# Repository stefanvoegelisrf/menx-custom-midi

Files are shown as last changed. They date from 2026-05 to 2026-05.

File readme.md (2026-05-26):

# Custom MIDI controller

This repository contains the code for my custom MIDI controller. The goal of the project is to make a face-shaped MIDI controller that is using I2C components and an ESP32. Code is written using Arduino IDE.

In this readme you can find the parts I used in the project, links to the project setup and helpful resources that I used in this project.

- [Custom MIDI controller](#custom-midi-controller)
  - [Project setup](#project-setup)
  - [Parts used in this project](#parts-used-in-this-project)
    - [Microcontroller - Waveshare ESP32-S3](#microcontroller---waveshare-esp32-s3)
      - [Documentation](#documentation)
    - [Slide potentiometers - Adafruit NeoSlider](#slide-potentiometers---adafruit-neoslider)
      - [Documentation](#documentation-1)
    - [Rotary Encoders - Adafruit Rotary Encoder](#rotary-encoders---adafruit-rotary-encoder)
      - [Documentation](#documentation-2)
    - [Buttons - Adafruit NeoKey 1x4](#buttons---adafruit-neokey-1x4)
      - [Documentation](#documentation-3)
  - [What is I2C](#what-is-i2c)
    - [I2C and Arduino](#i2c-and-arduino)
    - [I2C and Adafruit](#i2c-and-adafruit)
  - [Resources](#resources)

## Project setup

I have split the project setup into two parts.

[Project setup - Hardware](./project-setup-hardware.md) covers the hardware part of the project: 3D printing the controller case, soldering the parts, soldering the I2C addresses and connecting the components.

[Project setup - Software](./project-setup-software.md) covers the software part of the project: Setting up the development environment and code explanations.

## Parts used in this project

This project makes use of components by Adafruit which are connected via I2C (STEMMAT QT / QWIIC) for controlling MIDI. The components are connected to an ESP32.

### Microcontroller - Waveshare ESP32-S3

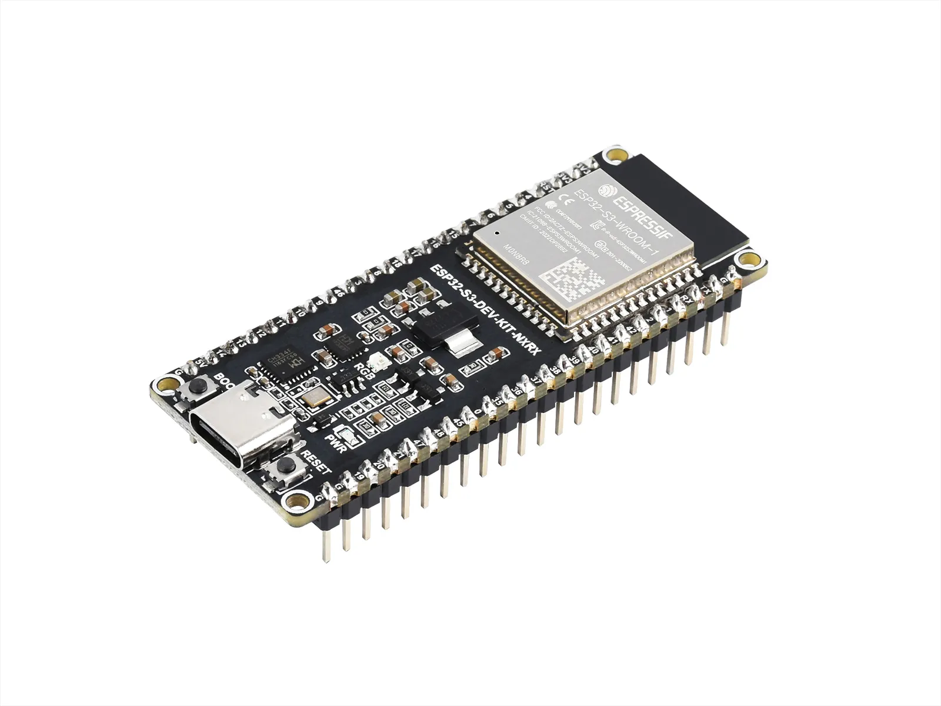
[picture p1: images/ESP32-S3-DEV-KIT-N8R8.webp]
Waveshare ESP32-S3 Product Image


> Product Link: [waveshare.com - ESP32-S3-DEV-KIT-NXRX](https://docs.waveshare.com/ESP32-S3-DEV-KIT-N8R8)

This ESP32 is used for receiving the signals from the components used, handles controlling the LEDs of the components and sends the MIDI signals over USB.

Number of components in this project: 1

#### Documentation

- [waveshare.com - ESP32-S3-DEV-KIT-NXRX](https://docs.waveshare.com/ESP32-S3-DEV-KIT-N8R8)

### Slide potentiometers - Adafruit NeoSlider

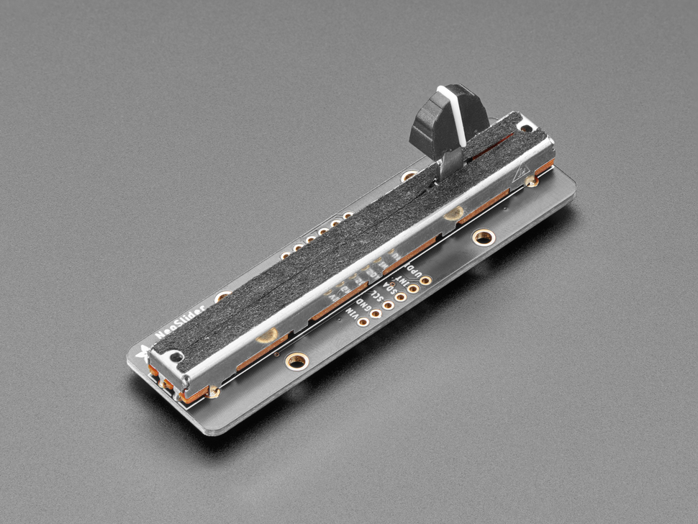
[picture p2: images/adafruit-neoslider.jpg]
Adafruit NeoSlider Product Image


> Product Link: [adafruit.com - Adafruit NeoSlider I2C QT Slide Potentiometer with 4 NeoPixels - STEMMA QT / Qwiic](https://www.adafruit.com/product/5295)

The slide potentiometers are used for representing the eyebrows of the face. I use custom slider caps. The 3D print file for these can be found [here - TODO: add link]().

Number of components in this project: 2

#### Documentation

- [learn.adafruit.com - Adafruit Neoslider](https://cdn-learn.adafruit.com/downloads/pdf/adafruit-neoslider.pdf)
- [learn.adafruit.com - Adafruit NeoSlider Downloads](https://learn.adafruit.com/adafruit-neoslider/downloads)

### Rotary Encoders - Adafruit Rotary Encoder

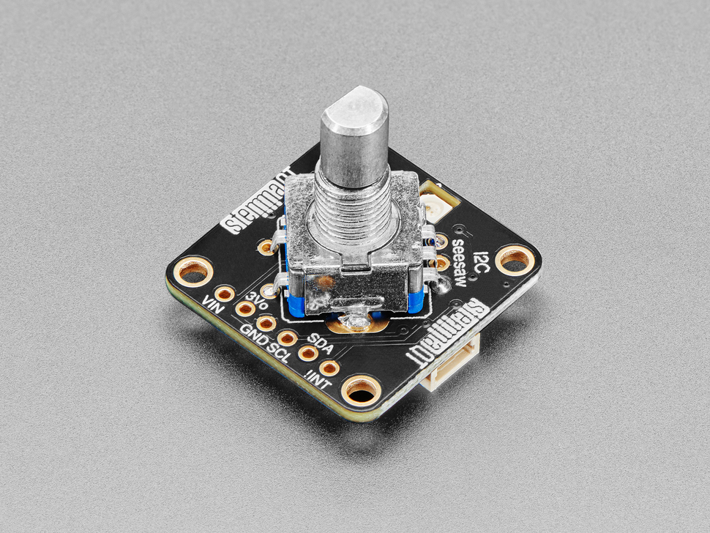
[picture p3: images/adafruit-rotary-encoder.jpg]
Adafruit Rotary Encoder Product Image


> Product Link: [Adafruit I2C Stemma QT Rotary Encoder Breakout with Encoder - STEMMA QT / Qwiic](https://www.adafruit.com/product/5880)

The rotary encoders are used for representing the eyes, noseholes and earrings of the face. I use custom encoder caps. The 3D print file for these can be found here: [EarringRotary.stl](./3d-print-parts/EarringRotary.stl), [Eyeknob_1.stl](./3d-print-parts/Eyeknob_1.stl) and [NoseRotary.stl](./3d-print-parts/NoseRotary.stl).

Number of components in this project: 6

#### Documentation

- [learn.adafruit.com - Adafruit I2C QT Rotary Encoder](https://cdn-learn.adafruit.com/downloads/pdf/adafruit-i2c-qt-rotary-encoder.pdf)
- [learn.adafruit.com - Adafruit I2C QT Rotary Encoder Downloads](https://learn.adafruit.com/adafruit-i2c-qt-rotary-encoder/downloads)

### Buttons - Adafruit NeoKey 1x4

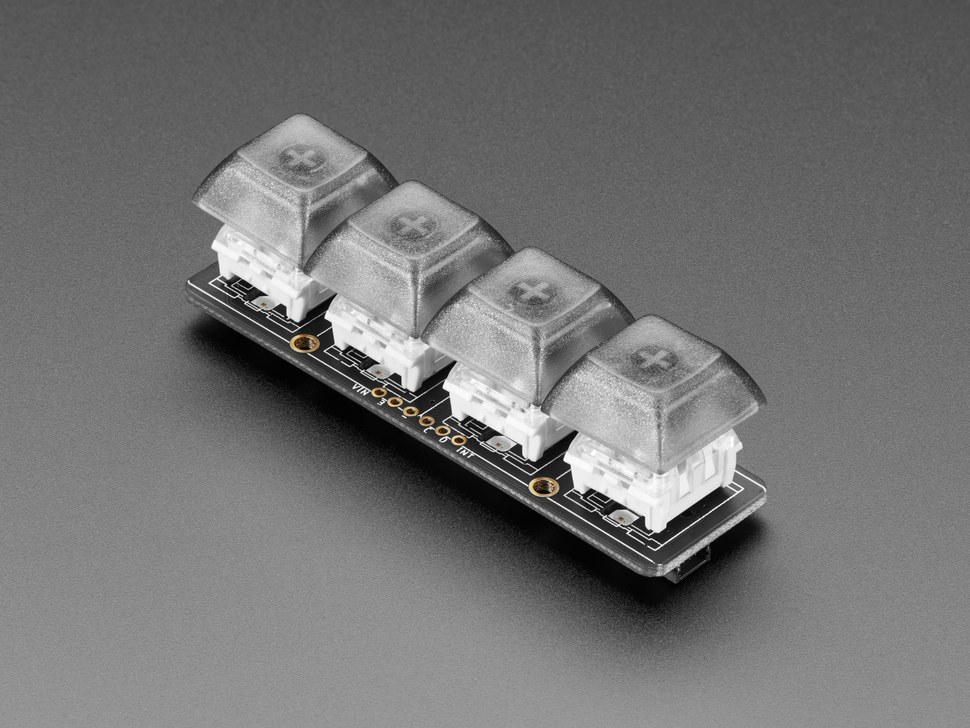
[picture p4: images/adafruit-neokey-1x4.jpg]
Adafruit NeoKey 1x4 Product Image


> Product Link: [adafruit.com - NeoKey 1x4 QT I2C - Four Mechanical Key Switches with NeoPixels - STEMMA QT / Qwiic](https://www.adafruit.com/product/4980)

The buttons are used for representing the teeth of the face. I use standard parts for the key switches and key caps. These are:
- [adafruit.com - Kailh Mechanical Key Switches - Linear Black - 10 pack - Cherry MX Black Compatible](https://www.adafruit.com/product/4953)
- [adafruit.com - Translucent Keycaps for MX Compatible Switches - 10 pack](https://www.adafruit.com/product/4956)

Number of components in this project: 2

#### Documentation

- [learn.adafruit.com - NeoKey 1x4 QT I2C](https://learn.adafruit.com/neokey-1x4-qt-i2c)
- [learn.adafruit.com - NeoKey 1x4 QT I2C Downloads](https://learn.adafruit.com/neokey-1x4-qt-i2c/downloads)

## What is I2C

Inter-integrated circuit (I2C) is a protocol used to connect and transfer data between my main processor (ESP32) and my components (Rotary encoders, sliders and buttons) using simple wiring.

Each component has a unique identification number assigned to it, so I can send or request data from the correct component.

I2C uses two lines to connect the devices:
- SDA (Serial Data): The actual data sent back and forth between processor and components
- SCL (Serial Clock): The pulsing signal to keep the devices synchronized

### I2C and Arduino

I2C in Arduino is handled with the [Wire Library](https://docs.arduino.cc/learn/communication/wire/#wire-library).

### I2C and Adafruit

The components that I use are from Adafruit and they have 5 connectors:
- VIN: Power pin, which can be supplied with 3 - 5 VDC. The components can regulate the voltage.
- 3Vo: 3.3V output from the voltage regulator
- GND: Ground
- SCL: I2C clock
- SDA: I2C data

## Resources

- [learn.adafruit.com - Adafruit STEMMA & STEMMA QT](https://learn.adafruit.com/introducing-adafruit-stemma-qt/what-is-stemma)
- [learn.adafruit.com - I2C address list](https://learn.adafruit.com/i2c-addresses/the-list)
- [docs.arduino.com - Inter-Integrated Circuit (I2C) Protocol](https://docs.arduino.cc/learn/communication/wire/)

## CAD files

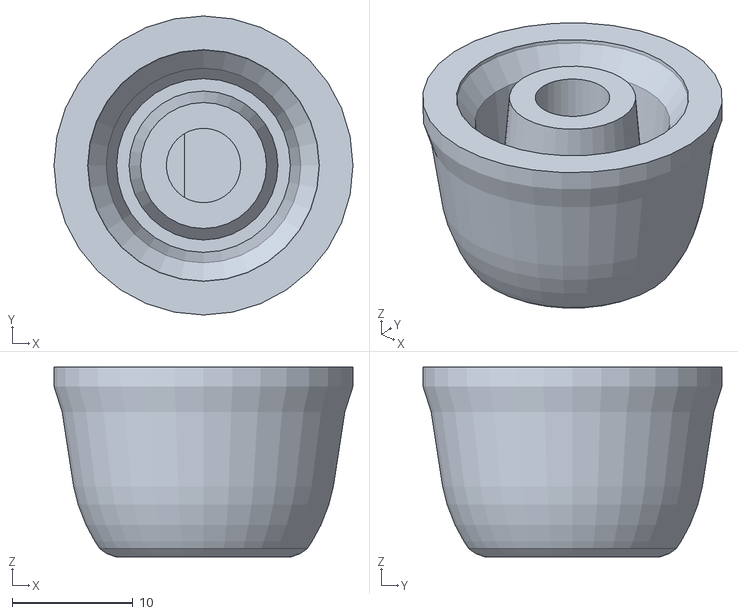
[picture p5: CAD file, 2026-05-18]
3d-print-parts/NoseRotary.stl
24.8 x 24.8 x 15.7

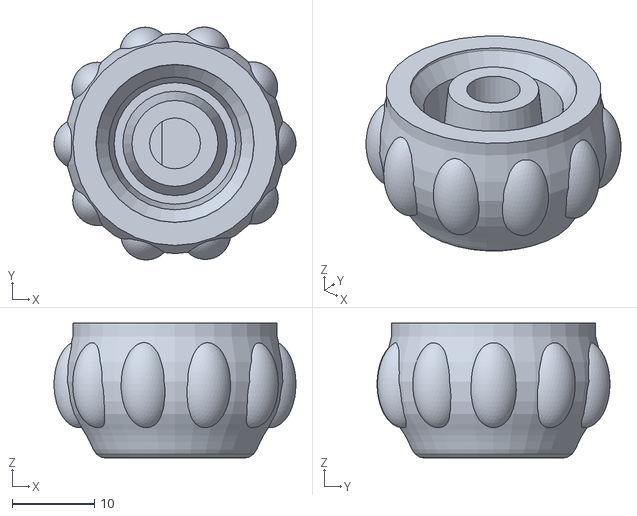
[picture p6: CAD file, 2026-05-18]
3d-print-parts/EarringRotary.stl
29.4 x 28.3 x 16.4

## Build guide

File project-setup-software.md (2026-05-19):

# Project Setup - Software

Below is a description of what is required to get the software of this project to work.

- [Project Setup - Software](#project-setup---software)
  - [Prerequisites](#prerequisites)
    - [Install Arduino IDE](#install-arduino-ide)
    - [Install Adafruit Seesaw library](#install-adafruit-seesaw-library)
    - [Install MIDI Library](#install-midi-library)
    - [Install ESP32 Boards](#install-esp32-boards)
    - [MIDI definition](#midi-definition)
      - [Data Value Mapping](#data-value-mapping)
      - [MIDI assignment](#midi-assignment)
  - [Troubleshooting and helpful stuff I learned](#troubleshooting-and-helpful-stuff-i-learned)
    - [No serial messages received](#no-serial-messages-received)
    - [No seesaw chip found](#no-seesaw-chip-found)
    - [Testing MIDI](#testing-midi)
    - [Enable MIDI](#enable-midi)
    - [Automating the build process and making it configurable](#automating-the-build-process-and-making-it-configurable)
  - [Resources](#resources)

## Prerequisites

In order to get started with the development, we need to set up a few things first.

### Install Arduino IDE

To develop this project, we use the Arduino IDE, as it is simple to use and can help us bundling the code correctly for our ESP32.

To install it, download it from [arduino.cc](https://www.arduino.cc/en/software/) and follow the installation process.

### Install Adafruit Seesaw library

The Adafruit components used in this project all have seesaw chips, so we need to install the seesaw library inside of the Arduino IDE to communicate with these chips.

To install it, go to the library manager and search for `adafruit seesaw` and install the library.

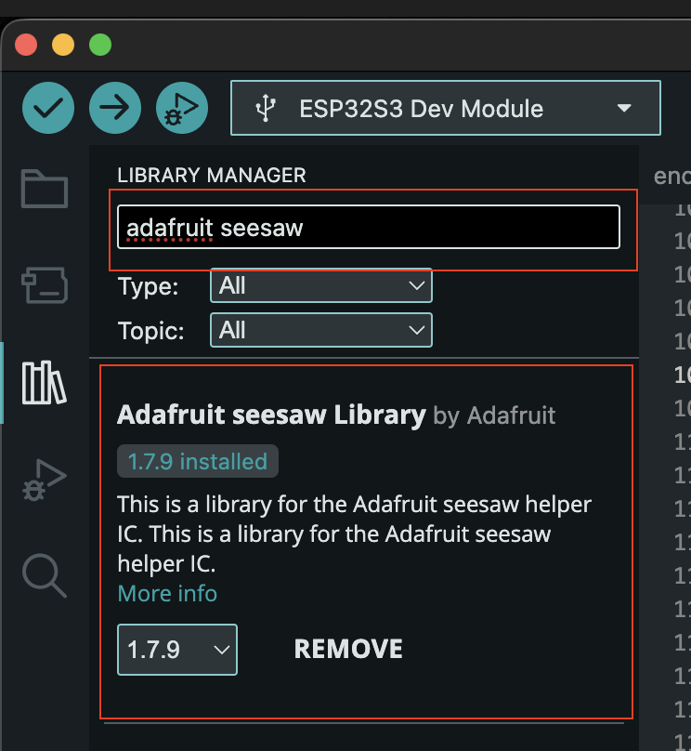
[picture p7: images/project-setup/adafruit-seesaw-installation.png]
Screenshot for Adafruit Seesaw library installation inside of Arduino IDE


### Install MIDI Library

This project transmits the values of the components via MIDI over USB and MIDI over BLE. A simple library to achieve this is called [Control-Surface](https://github.com/tttapa/Control-Surface) which also supports ESP32.

To install it, go to the library manager and search for `control surface`and install the library.

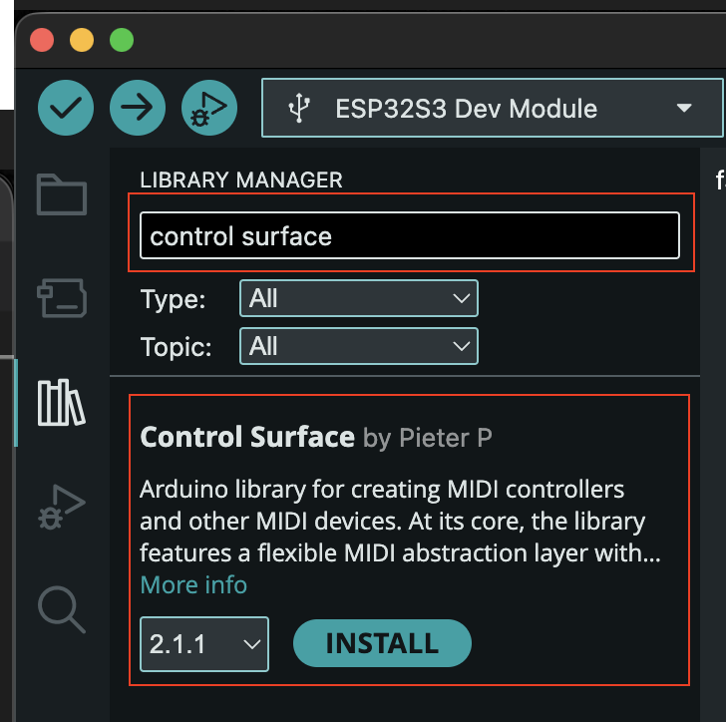
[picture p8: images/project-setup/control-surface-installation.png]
Screenshot for Control Surface library installation inside of Arduino IDE


### Install ESP32 Boards

As we use an ESP32 board in this project, we need to add the board configuration.

To do so, open the board manager and search for `esp32` and install the board configurations.

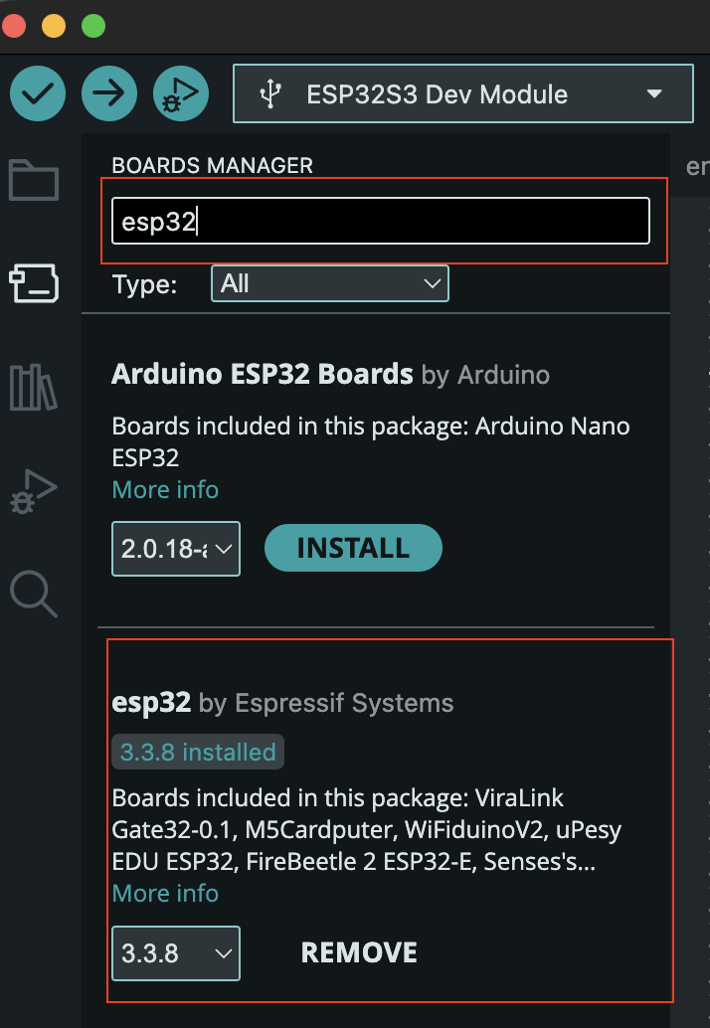
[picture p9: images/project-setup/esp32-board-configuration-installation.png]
Screenshot for ESP32 board configuration installation inside of Arduino IDE


### MIDI definition

My layout enables me to do a MIDI mapping to two channels. Like this I can assign 3 rotary encoders, 1 slider and 4 keys to each channel.

| MIDI Channel 1 | MIDI Channel 2 |
| --- | --- |
| Left Slider | Right Slider |
| Left Eye Rotary Encoder  | Right Eye Rotary Encoder  |
| Left Nose Rotary Encoder | Right Nose Rotary Encoder |
| Left Ear Rotary Encoder  | Right Ear Rotary Encoder  |
| Top 4 Keys | Bottom 4 Keys |

#### Data Value Mapping

The values that I receive from my components need to be mapped to MIDI values. The table below lines out how this is done:

| Hardware Action | MIDI Message Type | Data 1 (Identification) | Data 2 (Value) |
| --- | --- | --- | --- |
| Slider Movement | Control Change (CC) | CC Number | 0 to 127 |
| Encoder Turn Right | Control Change (CC) | CC Number | 1 |
| Encoder Turn Left  | Control Change (CC) | CC Number | 127 |
| Encoder/Key Press  | Note On or CC | Note/CC Number | 127 |
| Encoder/Key Lift | Note Off or CC | Note/CC Number | 0 |

#### MIDI assignment

Each of the components has to send unique values, the table below outlines the assigned values. This is the same for both MIDI channels.

| Component | Control Change | Note |
| --- | --- | ---- |
| Slider | 10 | |
| Eye Rotary Encoder  | 20 (Rotation), 21 (Switch) | 36 |
| Nose Rotary Encoder | 22 (Rotation), 23 (Switch) | 37 |
| Ear Rotary Encoder  | 24 (Rotation), 25 (Switch) | 38 |
| Key 1 | 26 | 40 |
| Key 2 | 27 | 41 |
| Key 3 | 28 | 42 |
| Key 4 | 29 | 43 |

## Troubleshooting and helpful stuff I learned

I have run into some issues in this project and here is a list of issues that I ran into, so if I run into them again, I know what the issue is and how to solve it.

### No serial messages received

I had the issue that I did not receive serial messages from my board, which sucks when trying to debug the project.

The issue was, that I had the setting `USB CDC On Boot` on `Disabled`. To receive the serial messages, set this to `Enabled`.

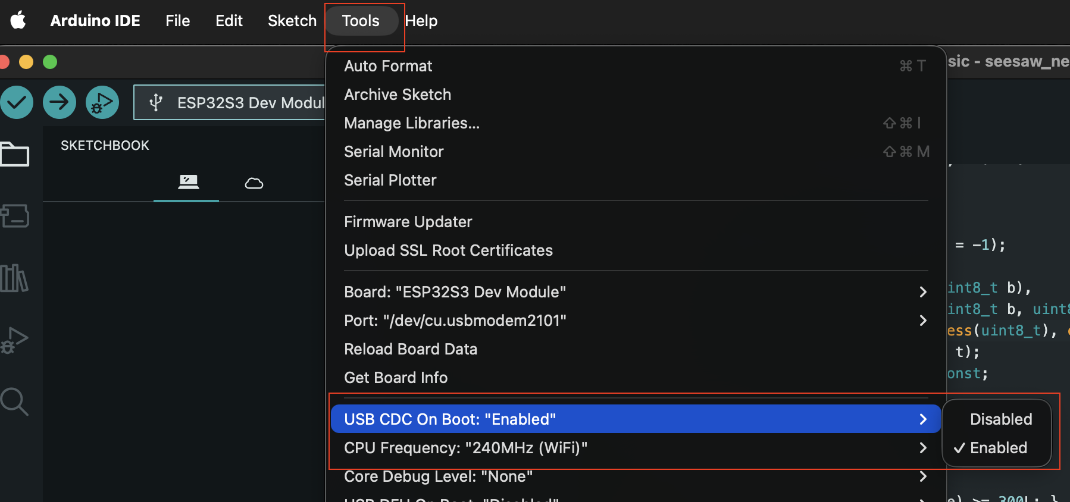
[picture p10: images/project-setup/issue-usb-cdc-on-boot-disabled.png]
Screenshot of setting USB CDC On Boot to Enabled inside of Arduino IDE


### No seesaw chip found

When using an ESP32, we can define the I2C pins freely and most likely, they will not be the standard I2C pins. To change this, we can set the pins manually in the Wire library and then pass the pointer of Wire to the Adafruit seesaw library.

```cpp
#define I2C_SDA 14
#define I2C_SCL 13

....

Adafruit_seesaw Sliders[2] = {
  Adafruit_seesaw(&Wire1),
  Adafruit_seesaw(&Wire1)
};

Adafruit_NeoKey_1x4 NeoKeyButtons[KEY_ROWS][KEY_COLUMNS / 4] = {
  { Adafruit_NeoKey_1x4(BUTTONS1_ADDRESS, &Wire1) },
  { Adafruit_NeoKey_1x4(BUTTONS2_ADDRESS, &Wire1) },
};

...

void setup() {
  // Set ESP32 pins manually, as they are not on the default pins
  Wire1.setPins(I2C_SDA, I2C_SCL);
}
```

### Testing MIDI

In order to troubleshoot if any and if the correct MIDI messages arrive on the receiving device, we can use a MIDI monitor application, e.g. [snoize.com. - MIDI Monitor](https://www.snoize.com/MIDIMonitor/)

### Enable MIDI

In order for the ESP32 to act as a MIDI device, we need to change some settings in Arduino IDE.

First, we need to set the USB mode to TinyUSB:

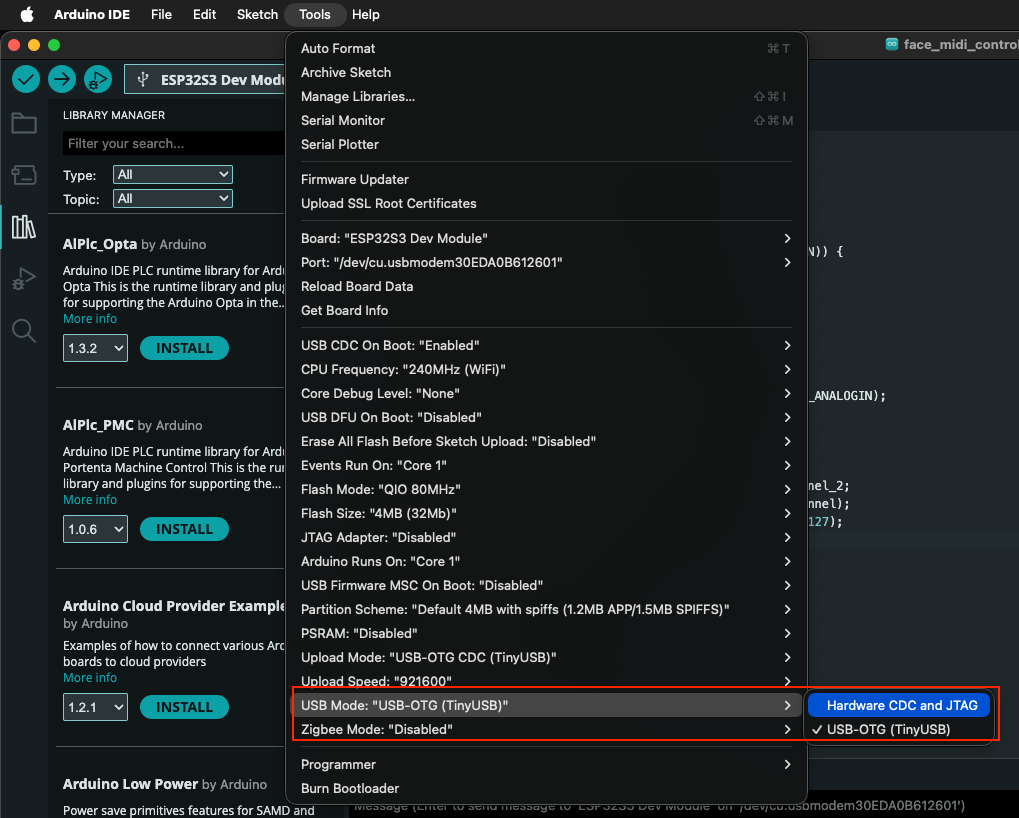
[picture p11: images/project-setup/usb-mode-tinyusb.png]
Screenshot of setting USB mode to TinyUSB inside of Arduino IDE


Then, to be able to upload new firmware onto the controller, we also need to set the upload mode to TinyUSB:

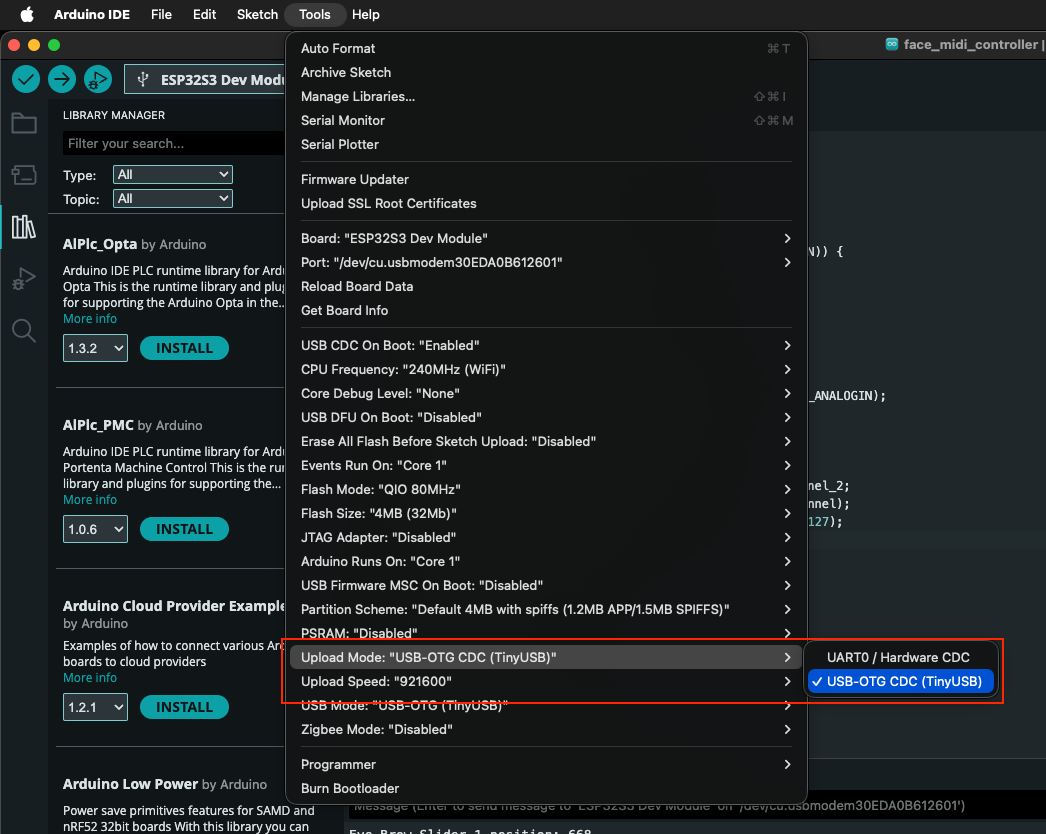
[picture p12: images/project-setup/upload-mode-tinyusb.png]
Screenshot of setting upload mode to TinyUSB inside of Arduino IDE


### How to connect MIDI BLE

In order to connect a MIDI device via BLE, we need to use the `Audio MIDI Setup` application of MacOS and the open the `MIDI Studio` via `Window` -> `Show MIDI Studio`.

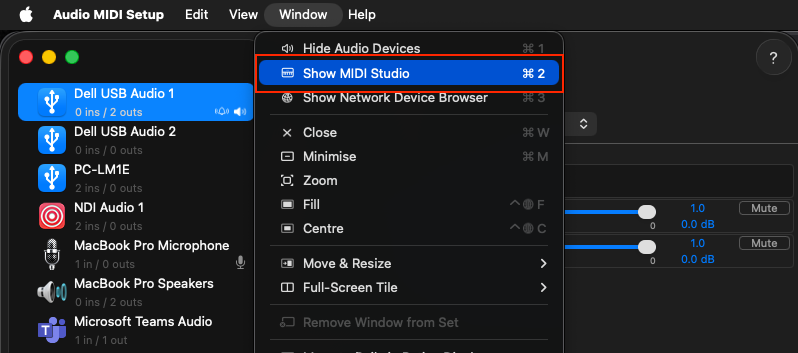
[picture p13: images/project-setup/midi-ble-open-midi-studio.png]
Screenshot showing how to open MIDI Studio


Once we have MIDI Studio open, we can click on the Bluetooth icon to search for our device and connect to it.

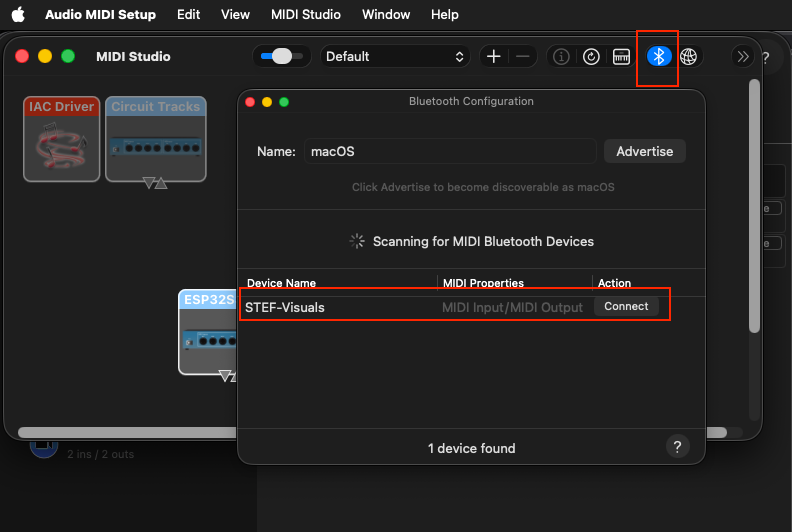
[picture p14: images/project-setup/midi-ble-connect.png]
Screenshot showing how to connect to MIDI BLE device


### Automating the build process and making it configurable

https://platformio.org/

## Resources

- [learn.adafruit.com - Adafruit Seesaw](https://learn.adafruit.com/adafruit-seesaw-atsamd09-breakout/overview)
- [learn.adafruit.com - Adafruit NeoSlider Arduino](https://learn.adafruit.com/adafruit-neoslider/arduino)
- [docs.waveshare.com - ESP32-S3-DEV-KIT-N8R8 Development Environment Setup Arduino](https://docs.waveshare.com/ESP32-S3-DEV-KIT-N8R8/Development-Environment-Setup-Arduino)
- [docs.waveshare.com - ESP32 Arduino IDE Setup](https://docs.waveshare.com/ESP32-Arduino-Tutorials/Arduino-IDE-Setup)
- [learn.adafruit.com - Arduino MIDI Example](https://learn.adafruit.com/adafruit-midi-featherwing/arduino-midi-example)
- [learn.adafruit.com - MIDI for Makers](https://learn.adafruit.com/midi-for-makers/overview)
- [tttapa.github.io - Control Surface Documentation](https://tttapa.github.io/Control-Surface/Doxygen/index.html)

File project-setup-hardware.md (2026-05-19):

# Project setup - Hardware

## 3D Printing

In this project, I have designed a custom case along with custom slider and rotary caps.

### Case

### Rotary encoder caps

I have not designed the rotary encoder caps from the ground up. Instead I have used freely available models and customized them to my liking.

In my project, the rotary encoders represent different parts of a face: eyes, nose holes and ear rings.

#### Print settings

In order to get fine details of the controller, I have set the layer height to the lowest possible setting.

In order to get good stability, I have set the infill density to a higher value.
TODO: add print settings(layer height, dense infill, no supports)

#### Eyes

> Base model: [thingiverse.com - Knob D shape rotary encoder by nanoBorg88](https://www.thingiverse.com/thing:3904056)

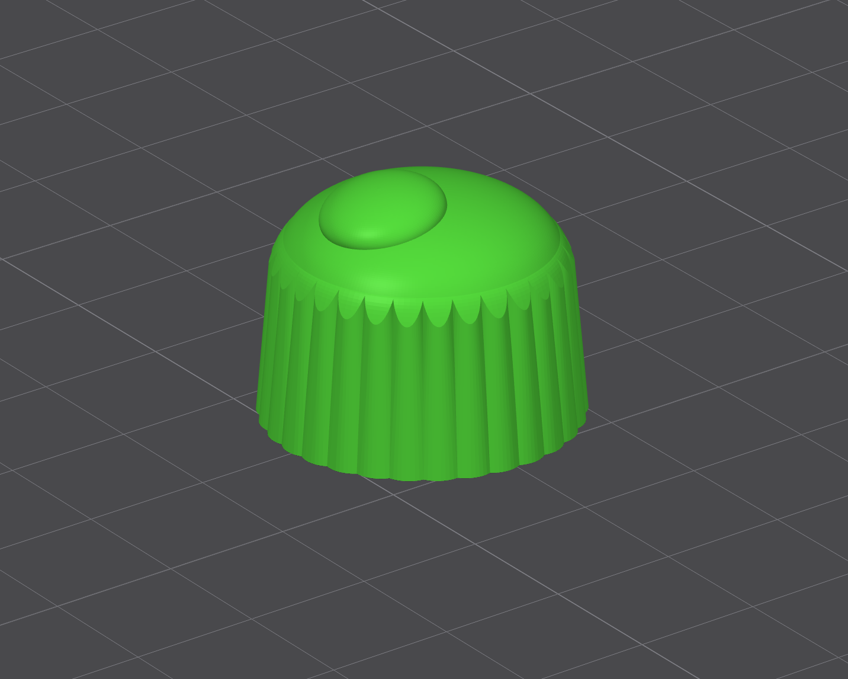
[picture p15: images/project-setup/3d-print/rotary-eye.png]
Eye rotary encoder cap


The 3d print file (STL) for the rotary encoder cap of the eyes can be found here: [Eyeknob_1.stl](./3d-print-parts/Eyeknob_1.stl)

Dimensions: 24.64mm x 24.52mm x 19.21mm

Number of parts required: 2

#### Nose Holes

> Base model: [thingiverse.com - Rotary Encoder Knob by fsda23](https://www.thingiverse.com/thing:5262791)

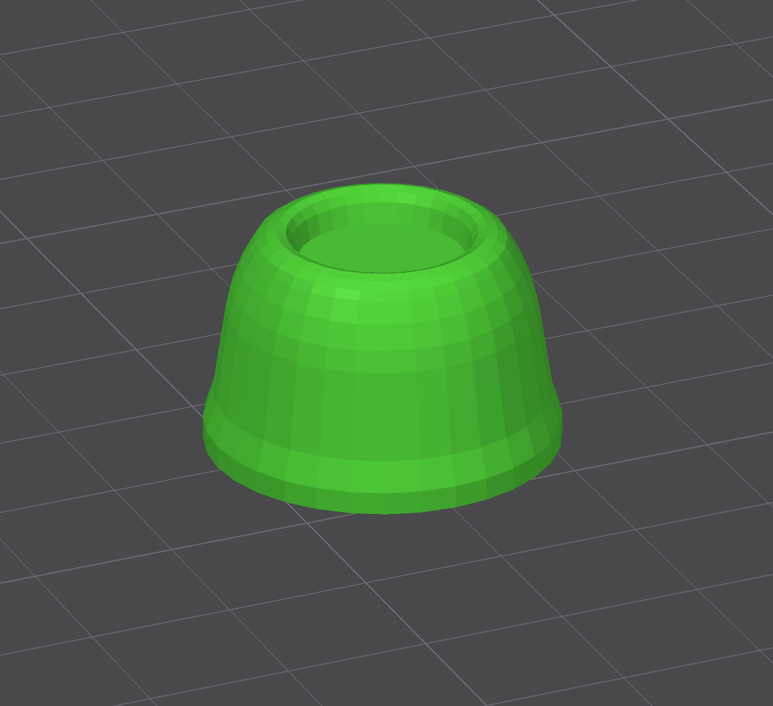
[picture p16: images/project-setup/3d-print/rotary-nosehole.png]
Nose hole rotary encoder cap


The 3d print file (STL) for the rotary encoder cap of the nose holes can be found here: [NoseRotary.stl](./3d-print-parts/NoseRotary.stl)

Dimensions: 24.75mm x 24.75mm x 15.72mm

Number of parts required: 2

#### Ear rings

> Base model: [thingiverse.com - Rotary Encoder Knob by fsda23](https://www.thingiverse.com/thing:5262791)

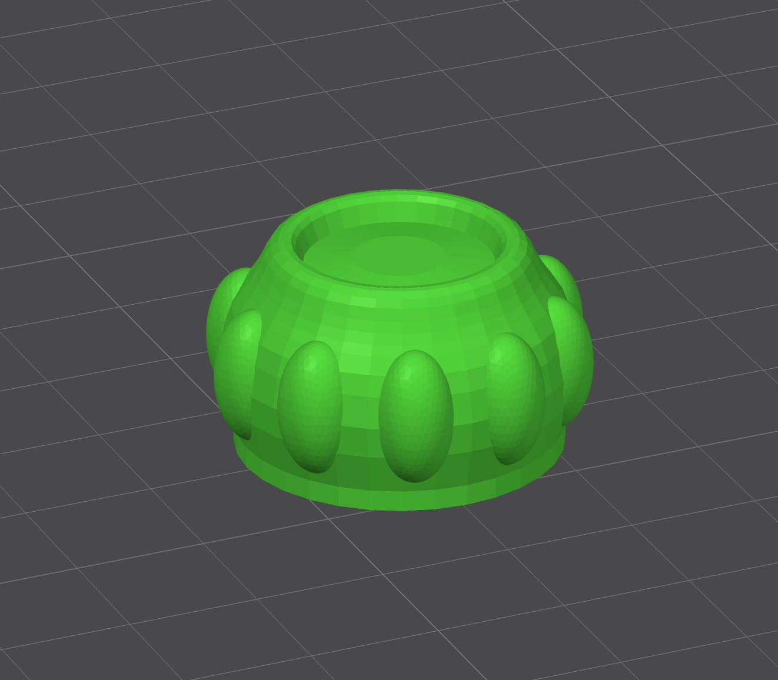
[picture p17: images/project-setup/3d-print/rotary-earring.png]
Ear ring rotary encoder cap


The 3d print file (STL) for the rotary encoder cap of the ear rings can be found here: [EarringRotary.stl](./3d-print-parts/EarringRotary.stl)

Dimensions: 29.36mm x 28.26mm x 16.36mm

Number of parts required: 2

### Slider caps

## Setting I2C addresses

## Connecting components

## Configuring the I2C addresses

As we need to have a unique I2C address for each component, these have to be set on the hardware. The Adafruit components that I use have address jumpers to do this.

The possible I2c addresses are:
- Slider: 0x30 - 0x3F (0x30, 0x31, 0x32, 0x33, 0x34, 0x35, 0x36, 0x37, 0x38, 0x39, 0x3A, 0x3B, 0x3C, 0x3D, 0x3E, 0x3F)
- Rotary Encoder: 0x36 - 0x3D (0x36, 0x37, 0x38, 0x39, 0x3A, 0x3B, 0x3C, 0x3D)
- Keys: 0x30 - 0x3F (0x30, 0x31, 0x32, 0x33, 0x34, 0x35, 0x36, 0x37, 0x38, 0x39, 0x3A, 0x3B, 0x3C, 0x3D, 0x3E, 0x3F)

### I2C address definition

| Component | Address |
| --- | --- |
| Slider 1 | 0x30 |
| Slider 2 | 0x31 |
| Rotary Encoder 1 | 0x36 |
| Rotary Encoder 2 | 0x37 |
| Rotary Encoder 3 | 0x38 |
| Rotary Encoder 4 | 0x39 |
| Rotary Encoder 5 | 0x3A |
| Rotary Encoder 6 | 0x3B |
| Keys 1 | 0x32 |
| Keys 2 | 0x33 |

### Slider address jumpers

> Guide for address jumpers: [learn.adafruit.com - Adafruit NeoSlider Address Jumpers](https://learn.adafruit.com/adafruit-neoslider/pinouts#address-jumpers-3107357)

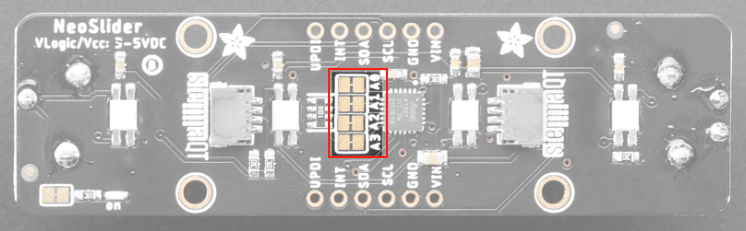
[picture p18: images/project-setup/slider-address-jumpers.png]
Slider Address Jumper Locations


The slider has four address jumpers. The default address of the slider is 0x30, which means that all the address jumpers are closed (not cut). By cutting the address jumpers, we add bits to the base of 0x30. In that way, we can achieve the addresses as layed out below:

| Component | Address | A0  | A1  | A2  | A3  |
| --- | --- | --- | --- | --- | --- |
| Slider 1  | 0x30 | L | L | L | L |
| Slider 2  | 0x31 | H | L | L | L |
| | 0x32 | L | H | L | L |
| | 0x33 | H | H | L | L |
| | 0x34 | L | L | H | L |
| | 0x35 | H | L | H | L |
| | 0x36 | L | H | H | L |
| | 0x37 | H | H | H | L |
| | 0x38 | L | L | L | H |
| | 0x39 | H | L | L | H |
| | 0x3A | L | H | L | H |
| | 0x3B | H | H | L | H |
| | 0x3C | L | L | H | H |
| | 0x3D | H | L | H | H |
| | 0x3E | L | H | H | H |
| | 0x3F | H | H | H | H |

- L -> low -> closed -> not cut
- H -> high -> open -> cut

### Rotary encoder address jumpers

> Guide for address jumpers: [learn.adafruit.com - Adafruit I2C QT Rotary Encoder Address Jumpers](https://learn.adafruit.com/adafruit-i2c-qt-rotary-encoder/pinouts#address-jumpers-3096023)

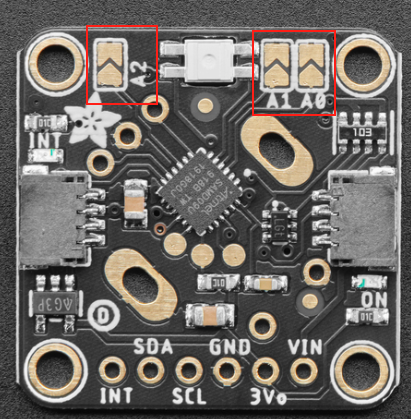
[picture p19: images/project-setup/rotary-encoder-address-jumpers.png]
Rotary Encoder Address Jumper Locations


The rotary encoders have three address jumpers, which can be left open (not soldered) or closed (soldered). To default address of the rotary encoders is 0x36, which means that all the address jumpers are open (not soldered). By soldering the address jumpers, we add bits to the base of 0x36. In that way, we can achieve the addresses as layed out below:

| Component | Address | A0  | A1  | A2  |
| --- | --- | --- | --- | --- |
| Rotary Encoder 1 | 0x36 | H | H | H |
| Rotary Encoder 2 | 0x37 | L | H | H |
| Rotary Encoder 3 | 0x38 | H | L | H |
| Rotary Encoder 4 | 0x39 | L | L | H |
| Rotary Encoder 5 | 0x3A | H | H | L |
| Rotary Encoder 6 | 0x3B | L | H | L |
| | 0x3C | H | L | L |
| | 0x3D | L | L | L |

- L -> low -> closed -> soldered
- H -> high -> open -> not soldered

### Keys address jumpers

> Guide for address jumpers: [learn.adafruit.com - Adafruit NeoKey Address Jumpers](https://learn.adafruit.com/neokey-1x4-qt-i2c/pinouts#address-jumpers-3098419)

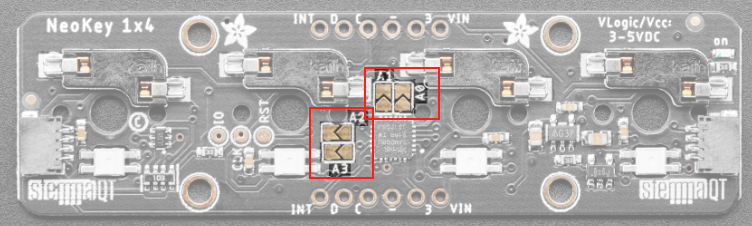
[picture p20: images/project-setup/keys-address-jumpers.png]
Keys Address Jumper Locations


The keys have four address jumpers, which can be left open (not soldered) or closed (soldered). The default address of the keys is 0x30, which means that all the address jumpers are open (not soldered). By soldering the address jumpers, we add bits to the base of 0x30. In that way, we can achieve the addresses as layed out below:

| Component | Address | A0  | A1  | A2  | A3  |
| --- | --- | --- | --- | --- | --- |
| | 0x30 | L | L | L | L |
| | 0x31 | H | L | L | L |
| Keys 1 | 0x32 | L | H | L | L |
| Keys 2 | 0x33 | H | H | L | L |
| | 0x34 | L | L | H | L |
| | 0x35 | H | L | H | L |
| | 0x36 | L | H | H | L |
| | 0x37 | H | H | H | L |
| | 0x38 | L | L | L | H |
| | 0x39 | H | L | L | H |
| | 0x3A | L | H | L | H |
| | 0x3B | H | H | L | H |
| | 0x3C | L | L | H | H |
| | 0x3D | H | L | H | H |
| | 0x3E | L | H | H | H |
| | 0x3F | H | H | H | H |

- L -> low -> open -> not soldered
- H -> high -> closed -> soldered

## Helpful things I learned

### How much power does a NeoPixel use/require

NeoPixels can draw up to 60 milliamps, meaning each pixel draws about 20 milliamps. If we want to display full bright white, the full 60 milliamps will be required as each pixel needs to be lit up the same amount. If we mix colors, the required milliamps will be lower. The rule of thumb of Adafruit is to calculate with 20 milliamps. For my 22 NeoPixels (Slider: 2x4 NeoPixel, Rotary Encoder: 6x1 NeoPixel, Keys: 2x4 NeoPixel), the amps calculation looks as follows:

- Rule of thumb calculation: 22 NeoPixels x 20 mA / 1000 = 0.4 amps minimum
- Maximum calculation: 22 NeoPixels x 60 mA / 1000 = 1.32 amps minimum

As these are the minimum amp requirements, it is good to always leave some headroom. Keep in mind that the board, the components themselves and also onboard pixels also need power.

### How much power does my board use/require

In order to know how much power my board uses or requires, I have to know which chip that it uses. The boards that I have checked for my project (ESP32-S3-DEV-KIT-N8R8 and LilyGo T7 S3) both use the ESP32-S3-WROOM-1 chip. The current consumption for this chip varies depending on what features are used. The current consumption in active mode can vary from 95 to 355 milliamps.

> Chip details: [files.waveshare.com - ESP32-S3 Wroom-1](https://files.waveshare.com/wiki/common/Esp32-s3-wroom-1_wroom-1u_datasheet_en.pdf)

#### Power management - low power

There are several options available for saving power. The official documentation lies out several scenarios: [docs.espressif.com - Low Power Mode](https://docs.espressif.com/projects/esp-idf/en/stable/esp32/api-guides/low-power-mode/index.html)

#### Power management - enable sleep

My controller does not need to be powered on all the time, so I could put it into sleep after a certain amount of time. For now, I won't do this, but this would be possible by looking at the documentation here: [docs.espressif.com - Sleep Modes](https://docs.espressif.com/projects/esp-idf/en/stable/esp32/api-reference/system/sleep_modes.html)

### How to know, how much power is available by using the 3.3V pin

The NeoPixels located on my Adafruit components are normally powered via 3.3V as this is the default connection for I2C cables. The board receives 5V which is then regulated down to 3.3V. This leads to the board providing a reduced amount of (milli) amps. As a NeoPixel can draw up to 60 milliamps, this can become critical when using a significant amount of NeoPixels. In my case, there are 22 NeoPixels in total. In order to find out, how much amps each NeoPixel can use, we can look at the voltage regulator that is present on a board. The information on the voltage regulator of the board can be found by looking at the schematics. For my project, I have looked at the following two boards:

#### Waveshare ESP32-S3-DEV-KIT-N8R8

> Product link: [docs.waveshare.com - ESP32-S3-DEV-KIT-N8R8](https://docs.waveshare.com/ESP32-S3-DEV-KIT-N8R8)

Schematic:

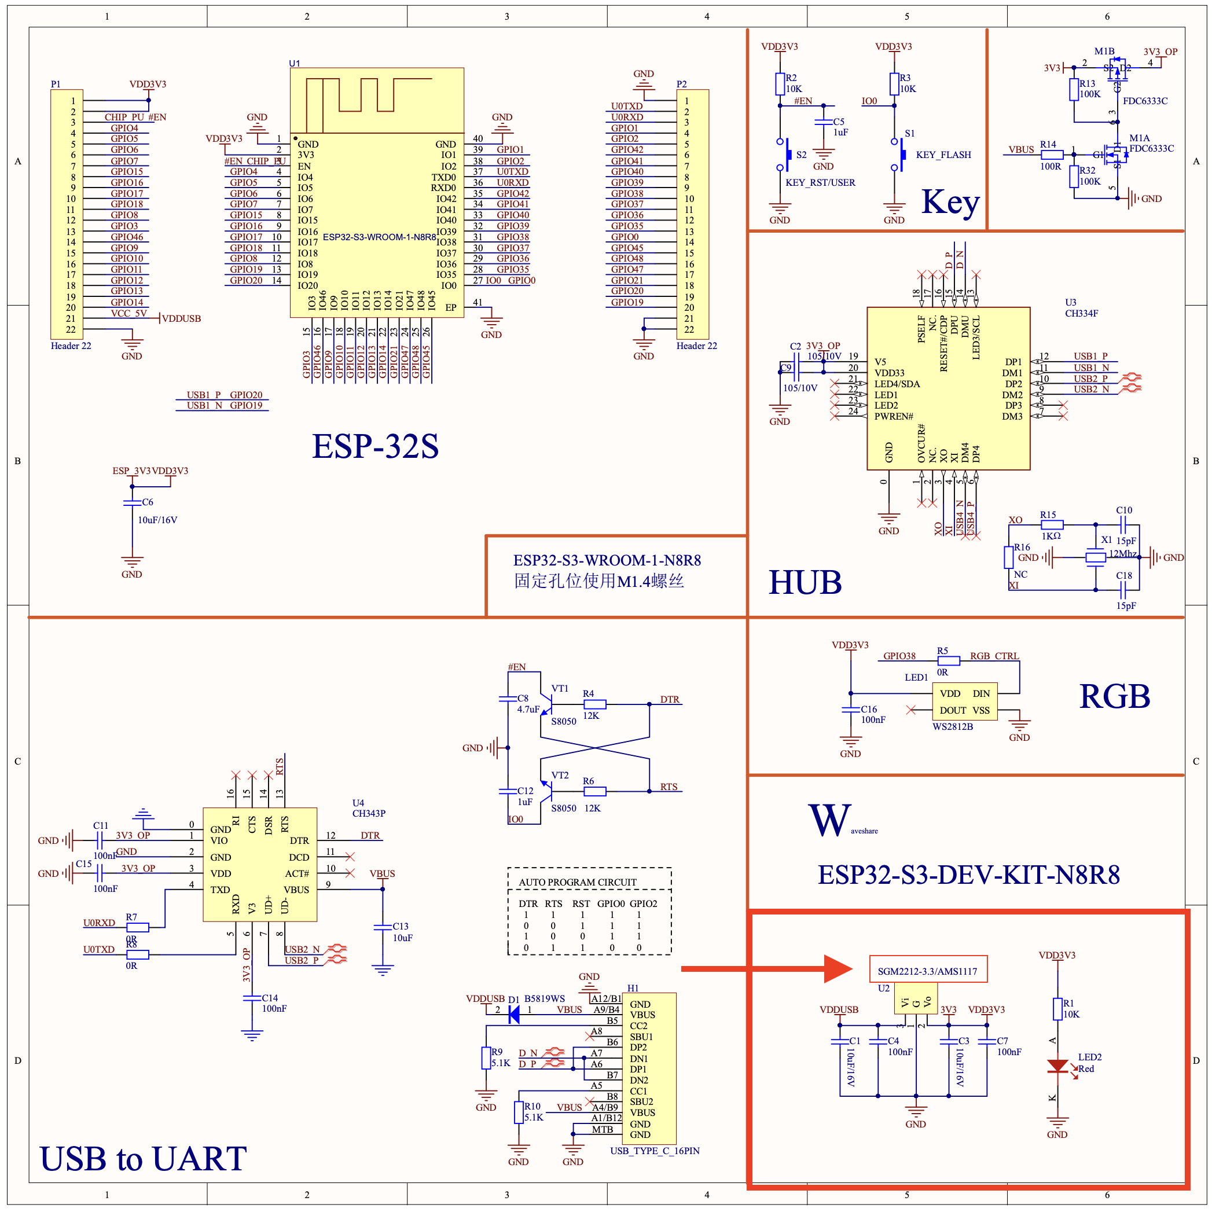
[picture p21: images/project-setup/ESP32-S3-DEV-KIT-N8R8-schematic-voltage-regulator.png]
Schematic of Waveshare ESP32-S3-DEV-KIT-N8R8 board highlighting voltage regulator


The voltage regulators mentioned for this board are `SGM2212` or `AMS1117`.

#### AMS1117

The AMS1117 provides an outpout current of 1 Amps.

> Technical details for `AMS1117`: [advanced-monolithic.com - AMS1117](http://www.advanced-monolithic.com/pdf/ds1117.pdf)

#### SGM2212

The SGM2212 provides an output current of 800 milliamps.

> Technical details for `SGM2212`: [sg-micro.com - SGM2212](https://www.sg-micro.com/product/SGM2212)

#### LilyGo T7 S3

> Product Link: [lilygo.cc - T7 S3](https://lilygo.cc/en-us/products/t7-s3)

Schematic:

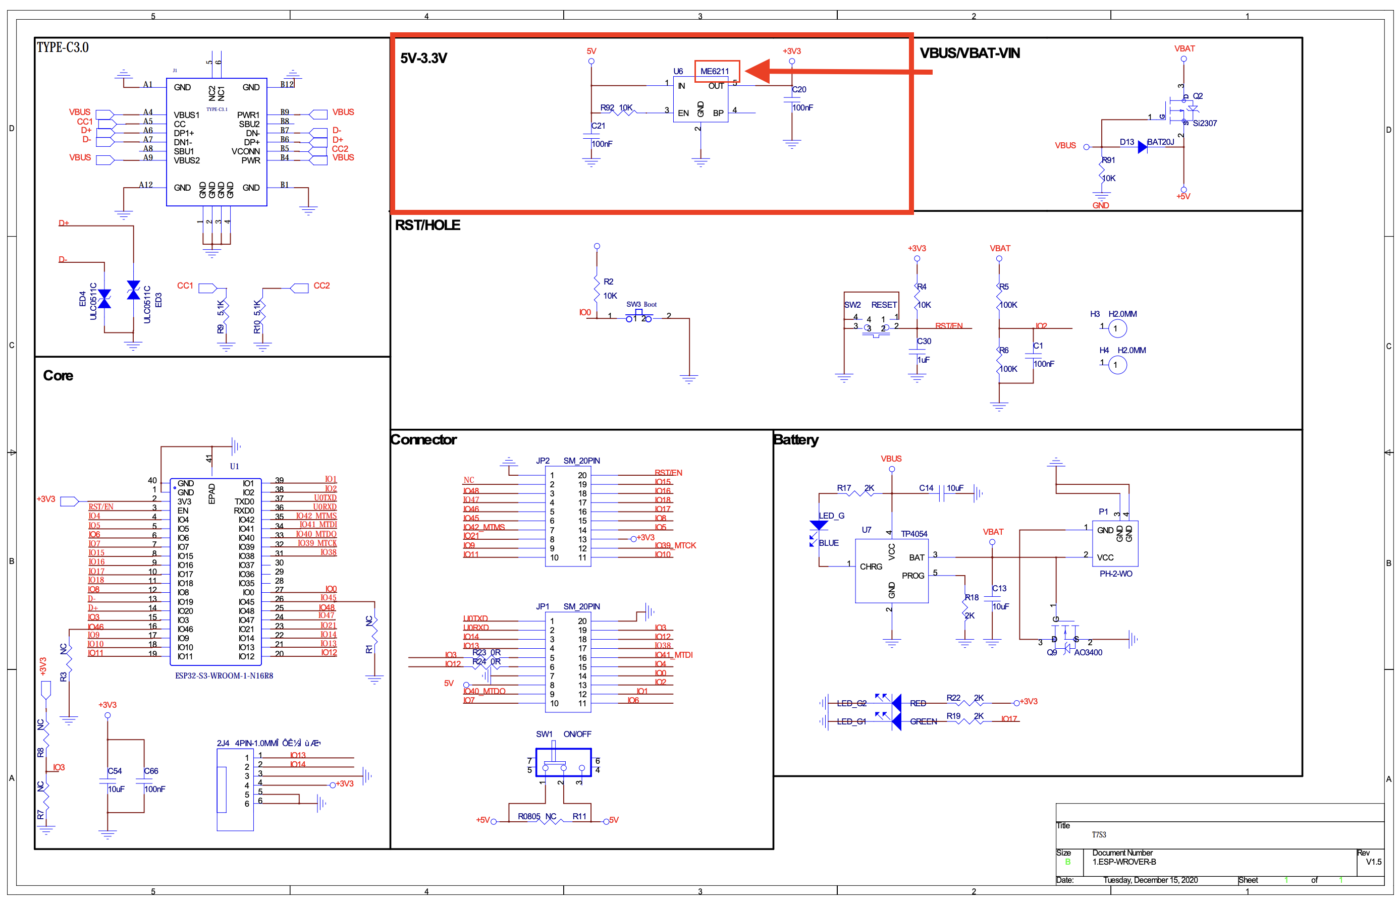
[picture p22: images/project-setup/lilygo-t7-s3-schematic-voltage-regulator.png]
Schematic of LilyGo T7 S3 board highlighting voltage regulator


The voltage regulator mentioned for this board is the `ME6211`.

##### ME6211

The ME6211 provides an output current of 500 milliamps.

> Technical details for `ME6211`: [github.com - ME6211](https://github.com/Edragon/Datasheet/blob/master/Microne/ME6211.pdf)

## Resources

- [learn.adafruit.com - Powering Neopixels](https://learn.adafruit.com/adafruit-neopixel-uberguide/powering-neopixels)

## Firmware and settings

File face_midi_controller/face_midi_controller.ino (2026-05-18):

#include "Adafruit_seesaw.h"
#include "Adafruit_NeoKey_1x4.h"
#include <Control_Surface.h>

#define I2C_SDA 14
#define I2C_SCL 13

#define ROTARY_SWITCH_PIN 24

#define SLIDER_ANALOGIN 18

#define SLIDER1_ADDRESS 0x30
#define SLIDER2_ADDRESS 0x31

#define ROTARY_EYE1_ADDRESS 0x36
#define ROTARY_EYE2_ADDRESS 0x37
#define ROTARY_NOSE1_ADDRESS 0x38
#define ROTARY_NOSE2_ADDRESS 0x39
#define ROTARY_EAR1_ADDRESS 0x3A
#define ROTARY_EAR2_ADDRESS 0x3B

#define BUTTONS1_ADDRESS 0x32
#define BUTTONS2_ADDRESS 0x33

#define KEY_ROWS 2
#define KEY_COLUMNS 4

#define ARRAY_SIZE(arr) (sizeof(arr) / sizeof(arr[0]))

const char* DEVICE_NAME = "STEF-Visuals";

const uint8_t FIXED_TRIGGER_VELOCITY = 127;

const uint8_t ENCODER_ADDRESSES[] = {
  ROTARY_EYE1_ADDRESS,
  ROTARY_EYE2_ADDRESS,
  ROTARY_NOSE1_ADDRESS,
  ROTARY_NOSE2_ADDRESS,
  ROTARY_EAR1_ADDRESS,
  ROTARY_EAR2_ADDRESS
};

const char* ENCODER_NAMES[] = {
  "Eye 1", "Eye 2", "Nose 1", "Nose 2", "Ear 1", "Ear 2"
};

Adafruit_seesaw RotaryEncoders[6] = {
  Adafruit_seesaw(&Wire1),
  Adafruit_seesaw(&Wire1),
  Adafruit_seesaw(&Wire1),
  Adafruit_seesaw(&Wire1),
  Adafruit_seesaw(&Wire1),
  Adafruit_seesaw(&Wire1)
};

int32_t EncoderPositions[] = { 0, 0, 0, 0, 0, 0 };

bool LastEncoderSwitchStates[] = { true, true, true, true, true, true };

const uint8_t SLIDER_ADDRESSES[] = {
  SLIDER1_ADDRESS,
  SLIDER2_ADDRESS
};

const char* SLIDER_NAMES[] = {
  "Eye Brow Slider 1", "Eye Brow Slider 2"
};

Adafruit_seesaw Sliders[2] = {
  Adafruit_seesaw(&Wire1),
  Adafruit_seesaw(&Wire1)
};

uint16_t SliderValues[] = { 0, 0 };

Adafruit_NeoKey_1x4 NeoKeyButtons[KEY_ROWS][KEY_COLUMNS / 4] = {
  { Adafruit_NeoKey_1x4(BUTTONS1_ADDRESS, &Wire1) },
  { Adafruit_NeoKey_1x4(BUTTONS2_ADDRESS, &Wire1) },
};

Adafruit_MultiNeoKey1x4 NeoKeys((Adafruit_NeoKey_1x4*)NeoKeyButtons, KEY_ROWS, KEY_COLUMNS / 4);

USBMIDI_Interface MidiUsb;
BluetoothMIDI_Interface MidiBle;

NeoKey1x4Callback buttonPressed(keyEvent e);

void setupEncoders() {
  for (int i = 0; i < ARRAY_SIZE(RotaryEncoders); i++) {
    Serial.print("Initializing ");
    Serial.print(ENCODER_NAMES[i]);
    Serial.print(" at address 0x");
    Serial.println(ENCODER_ADDRESSES[i], HEX);

    if (!RotaryEncoders[i].begin(ENCODER_ADDRESSES[i])) {
      Serial.print("Error: Couldn't find encoder: ");
      Serial.println(ENCODER_NAMES[i]);
      while (1) delay(10);
    }

    // Check product firmware version
    uint32_t version = ((RotaryEncoders[i].getVersion() >> 16) & 0xFFFF);
    if (version != 4991) {
      Serial.print("Error: Wrong firmware loaded on ");
      Serial.print(ENCODER_NAMES[i]);
      Serial.print("? Version: ");
      Serial.println(version);
      while (1) delay(10);
    }

    // Configure the built-in switch
    RotaryEncoders[i].pinMode(ROTARY_SWITCH_PIN, INPUT_PULLUP);

    // Get starting position
    EncoderPositions[i] = RotaryEncoders[i].getEncoderPosition();

    // Enable interrupts for the encoder
    RotaryEncoders[i].setGPIOInterrupts((uint32_t)1 << ROTARY_SWITCH_PIN, 1);
    RotaryEncoders[i].enableEncoderInterrupt();
  }

  Serial.println("All encoders started successfully!\n");
}

void setupSliders() {
  for (int i = 0; i < ARRAY_SIZE(Sliders); i++) {
    Serial.print("Initializing ");
    Serial.print(SLIDER_NAMES[i]);
    Serial.print(" at address 0x");
    Serial.println(SLIDER_ADDRESSES[i], HEX);

    if (!Sliders[i].begin(SLIDER_ADDRESSES[i])) {
      Serial.println(F("Slider not found!"));
      while (1) delay(10);
    }

    uint16_t pid;
    uint8_t year, mon, day;
    Sliders[i].getProdDatecode(&pid, &year, &mon, &day);
    if (pid != 5295) {
      Serial.println(F("Wrong slider PID"));
      while (1) delay(10);
    }
  }

  Serial.println("All sliders started successfully!\n");
}

void setupKeys() {
  if (!NeoKeys.begin()) {
    Serial.println("Could not start NeoKeys, check wiring?");
    while (1) delay(10);
  }

  Serial.println("NeoKeys started!");

  for (int y = 0; y < KEY_ROWS; y++) {
    for (int x = 0; x < KEY_COLUMNS; x++) {
      NeoKeys.registerCallback(x, y, buttonPressed);
    }
  }
}

void sendNoteOn(MIDIAddress midiAddress, uint8_t velocity) {
  MidiUsb.sendNoteOn(midiAddress, velocity);
  MidiBle.sendNoteOn(midiAddress, velocity);
}

void sendNoteOff(MIDIAddress midiAddress, uint8_t velocity) {
  MidiUsb.sendNoteOff(midiAddress, velocity);
  MidiBle.sendNoteOff(midiAddress, velocity);
}

void sendCc(MIDIAddress midiAddress, uint8_t value) {
  MidiUsb.sendCC(midiAddress, value);
  MidiBle.sendCC(midiAddress, value);
}

void checkEncoders() {
  for (int i = 0; i < ARRAY_SIZE(RotaryEncoders); i++) {
    // Read current position
    int32_t newPosition = RotaryEncoders[i].getEncoderPosition();

    Channel midiChannel = (i % 2 == 0) ? Channel_1 : Channel_2;

    if (newPosition != EncoderPositions[i]) {
      // Note: C cuts off the decimal places in this division, so we get the correct CC number
      // e.g. Rotary Encoder Eye 1 has i=0 -> i/2=0 -> 0*2=0, Rotary Encoder Eye 2 has i=1 -> i/2=0.5 -> C cuts off decimal -> 0*2=0
      MIDIAddress ccAddress = MIDIAddress(20 + (i / 2) * 2, midiChannel);
      int32_t difference = newPosition - EncoderPositions[i];
      sendCc(ccAddress, difference > 0 ? 1 : 127);

      EncoderPositions[i] = newPosition;
    }

    // Check if the encoder button is pressed
    // Note: The switch is active LOW (0 when pressed)
    bool currentSwitchState = RotaryEncoders[i].digitalRead(ROTARY_SWITCH_PIN);
    if (currentSwitchState != LastEncoderSwitchStates[i]) {
      MIDIAddress ccSwitchAddress = MIDIAddress(21 + (i / 2) * 2, midiChannel);
      MIDIAddress noteAddress = MIDIAddress(36 + (i / 2), midiChannel);

      if (!currentSwitchState) {  // Pressed
        sendCc(ccSwitchAddress, FIXED_TRIGGER_VELOCITY);
        sendNoteOn(noteAddress, FIXED_TRIGGER_VELOCITY);
      } else {
        sendCc(ccSwitchAddress, 0);
        sendNoteOff(noteAddress, 0);
      }
      LastEncoderSwitchStates[i] = currentSwitchState;
    }
  }
}

void checkSliders() {
  for (int i = 0; i < ARRAY_SIZE(Sliders); i++) {
    uint16_t sliderValue = Sliders[i].analogRead(SLIDER_ANALOGIN);
    if (sliderValue != SliderValues[i]) {
      Channel midiChannel = (i == 0) ? Channel_1 : Channel_2;
      MIDIAddress ccAddress = MIDIAddress(10, midiChannel);
      uint8_t midiValue = map(sliderValue, 0, 1023, 0, 127);
      sendCc(ccAddress, midiValue);
      SliderValues[i] = sliderValue;
    }
  }
}

void setup() {
  Serial.begin(115200);
  // Set ESP32 pins manually, as they are not on the default pins
  Wire1.setPins(I2C_SDA, I2C_SCL);

  setupSliders();
  setupEncoders();
  setupKeys();

  MidiBle.setName(DEVICE_NAME);
  MIDI_Interface::beginAll();
}

void loop() {
  checkEncoders();
  checkSliders();
  NeoKeys.read();
  MIDI_Interface::updateAll();
  // don't overwhelm serial port
  delay(10);
}

NeoKey1x4Callback buttonPressed(keyEvent e) {
  uint8_t keyIndex = e.bit.NUM;

  Channel midiChannel = (keyIndex < 4) ? Channel_1 : Channel_2;
  uint8_t offset = (keyIndex < 4) ? 0 : 4;

  uint8_t controlChangeNumber = 26 + (keyIndex - offset);
  uint8_t noteNumber = 40 + (keyIndex - offset);

  MIDIAddress ccAddress = MIDIAddress(controlChangeNumber, midiChannel);
  MIDIAddress noteAddress = MIDIAddress(noteNumber, midiChannel);

  if (e.bit.EDGE == SEESAW_KEYPAD_EDGE_RISING) {
    sendNoteOn(noteAddress, FIXED_TRIGGER_VELOCITY);
    sendCc(ccAddress, FIXED_TRIGGER_VELOCITY);

  } else if (e.bit.EDGE == SEESAW_KEYPAD_EDGE_FALLING) {
    sendNoteOff(noteAddress, 0);
    sendCc(ccAddress, 0);
  }

  return 0;
}

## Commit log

2026-05-18 add basic component documentation, add encoder basic example
2026-05-18 add number of components and I2C addresses
2026-05-18 add 3d print files, add I2c explanation
    [EarringRotary.stl, NoseRotary.stl]
2026-05-18 add I2C address definition
2026-05-18 update code for multiple rotary encoders
2026-05-18 add midi definition, rename arduino code file, add I2C info
2026-05-18 add i2c address configuration
2026-05-18 simplify code, pass wire to neokeys
2026-05-18 add control surface(midi) for button presses
2026-05-18 refactor, add code to for encoder midi
2026-05-19 add details for power calculation
2026-05-19 add power considerations
2026-05-19 rewrite power management stuff
